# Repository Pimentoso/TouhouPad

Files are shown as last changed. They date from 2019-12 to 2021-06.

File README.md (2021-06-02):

Ergonomic gamepad to play Touhou Project games. Left-hand controls shoot/slow/bomb, and right hand controls movement. The bomb button is supposed to be pressed with the left thumb.

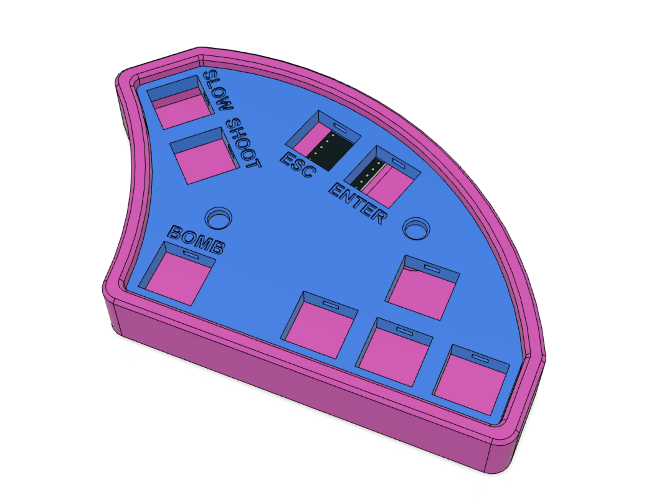
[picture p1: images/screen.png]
Rendering


More pictures at Thingiverse -> https://www.thingiverse.com/thing:4088449

## Materials needed

- 9 cherry MX compatible switches
- 9 keycaps
- 12mm M3 countersunk screws (2x) (10mm or 16mm should be fine as well)
- M3 nuts (2x)
- an Arduino Pro Micro (5v model)
- optionally, 9 Amoeba single switch PCBs for a cleaner wiring job
- soldering iron and wires
- a 3d printer

The pad has only 9 keys so we can just make a single row with 9 columns, so there's no need for diodes.

If you use the amoebas for the wiring, make sure to bridge the diode pads/holes since they're not used. This is easily done by placing some solder on the SMD diode pads until they are connected (you can also use a small strand of wire or a piece of diode leg)

## Building instructions

- Print the plate face down. Use 0.2mm layer height with no supports. The first layer has small text on it so print it slowly to ensure bed adhesion.
- Print the case. Punch open the screw holes, and push the M3 nuts into the hexagonal slots at the bottom.
- Insert the switches into the plate and handwire them to the Pro Micro (schematics are below).
- Slide the Pro Micro into its slot and drop the plate into the case.
- Screw the plate to the case making sure you aren't squeezing some wires on the screw poles.
- Flash the firmware (instructions below).
- Done!

## Wiring table

| matrix pin | firmware pin | pro micro pin |
| --- | --- | --- |
| Row 0 | F4 | A3 |
| Column 0 (left shift) | F5 | A2 |
| Column 1 (Z key) | F6 | A1 |
| Column 2 (X key) | F7 | A0 |
| Column 3 (left arrow) | D7 | 6 |
| Column 4 (down arrow) | C6 | 5 |
| Column 5 (right arrow) | D4 | 4 |
| Column 6 (up arrow) | D0 | 3 |
| Column 7 (esc key) | B1 | 15 |
| Column 8 (enter key) | D1 | 2 |

## Schematics

(note: it's the bottom view of the plate)

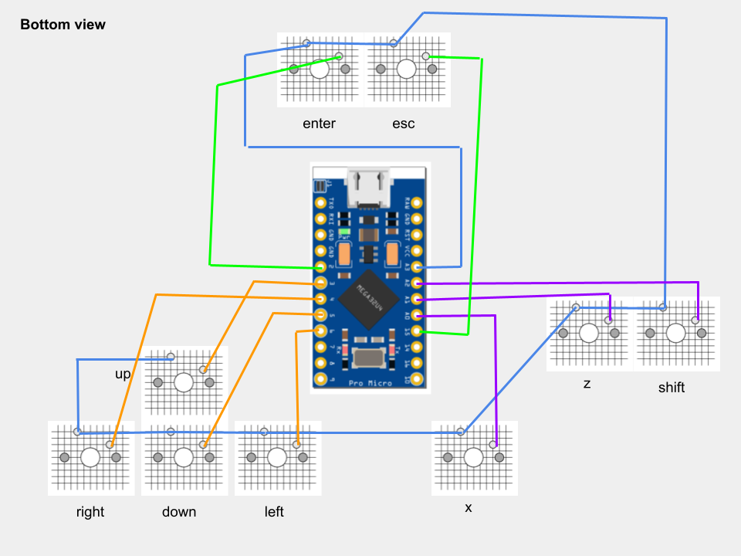
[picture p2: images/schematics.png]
Schematics


## Firmware

You can load the touhoupad.json file into https://kbfirmware.com/ and edit the keys. Use the compile function on that site to get the hex file.

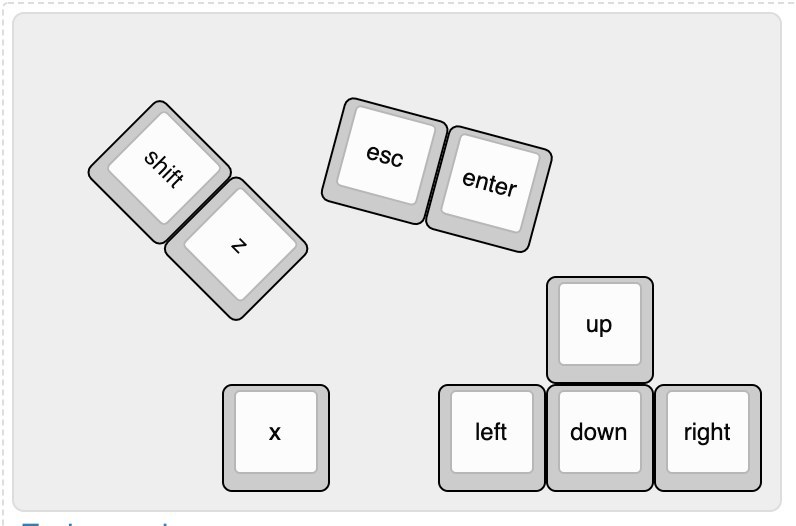
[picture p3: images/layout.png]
Layout


I use QMK toolbox [https://github.com/qmk/qmk_toolbox] for easy flashing. There's a precompiled hex file in the firmware folder.

If you need to flash it after assembling, there's a hole on the bottom you can use for shorting the RESET and GROUND pins, to enter flashing mode. Stick a bent paperclip in it or something.

## Keyboard Layout Editor link

http://www.keyboard-layout-editor.com/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

## 3d printing directions

- use 0.2mm layer height.
- print the plate face down and VERY slow on the first layer for the letters to come out decent.
- no support needed, just punch open the screw holes after printing.

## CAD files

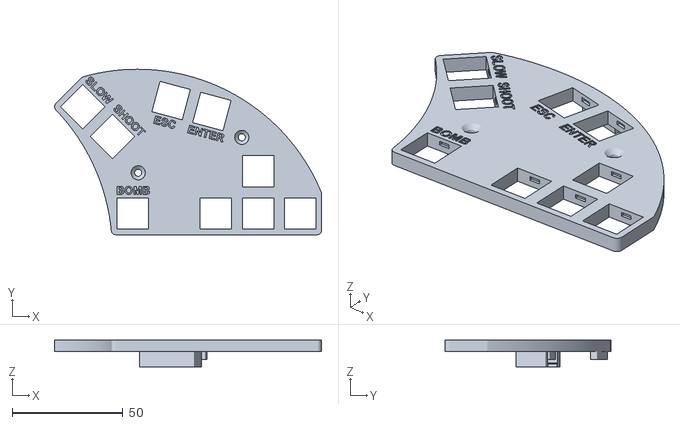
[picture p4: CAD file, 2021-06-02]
3d_models/Plate_v14.stl
120.6 x 74.8 x 12.0

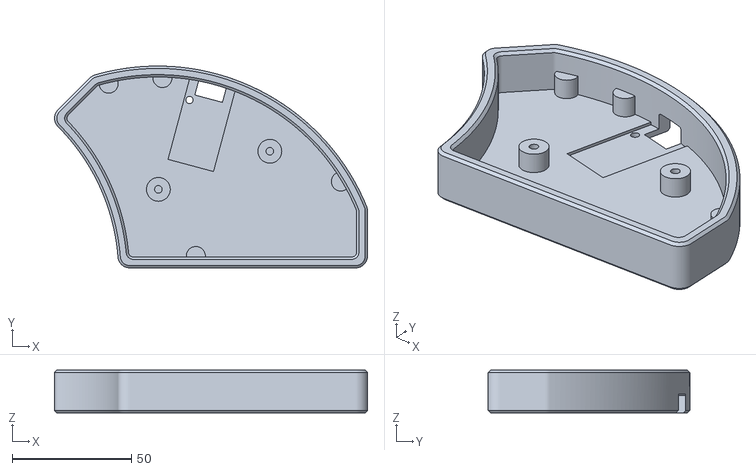
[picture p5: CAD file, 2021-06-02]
3d_models/Case_v14.stl
131.4 x 84.8 x 18.0

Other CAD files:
3d_models/Touhou pad v14.f3z

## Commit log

2021-04-14 Wiring table on readme
2021-04-16 added schematics to readme
2021-06-02 case and plate model fixes. Use countersunk screws.
    [Case.stl, Case_v14.stl, Plate.stl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]
